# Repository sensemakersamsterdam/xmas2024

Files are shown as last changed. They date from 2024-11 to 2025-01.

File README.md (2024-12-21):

# 2024 Christmas project

A colaboration between:
- The Sensmakers Amsterdam IoT community: www.sensemakersams.org
- The Amsterdam Public Library: www.oba.nl
- in2tech: www.in2tech.nl
- Matanga: www.matanga.nl

Subdirectories:
- *src* for the python source files,
- *elec* for the schematics and PCB design in KiCad, PDF and JLCPCB manifacture formats,
- *case* for the design of the case and acrylic parts of the case.

For more info consult [https://sensemakersams.org/xmas-2024-acrylic-lamp/](https://sensemakersams.org/xmas-2024-acrylic-lamp/)

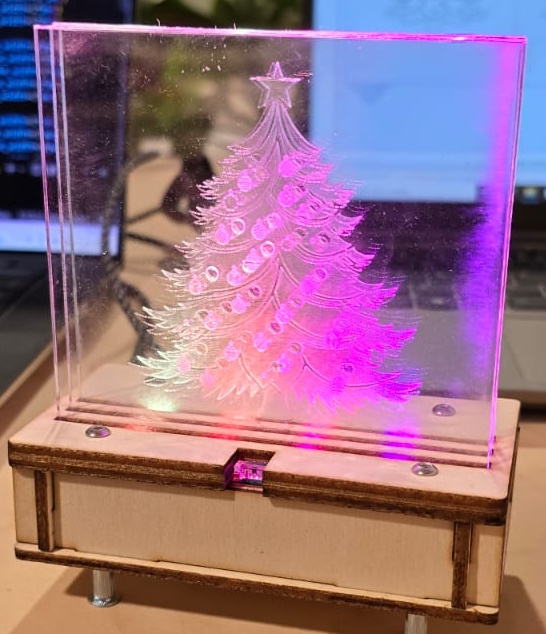
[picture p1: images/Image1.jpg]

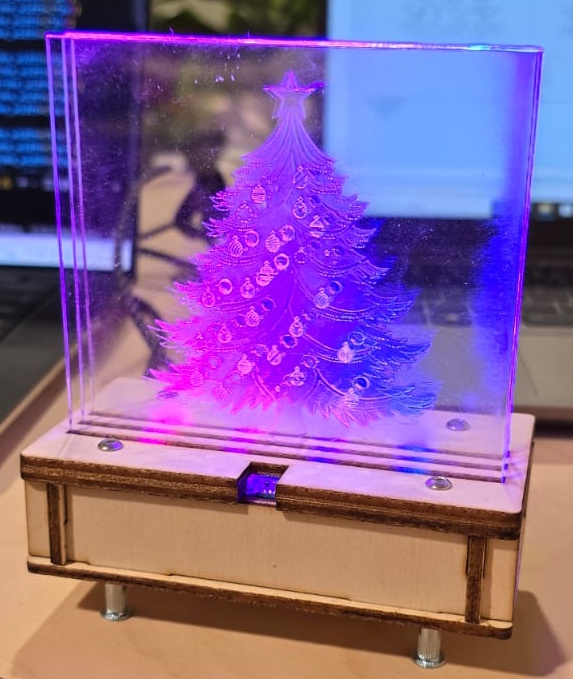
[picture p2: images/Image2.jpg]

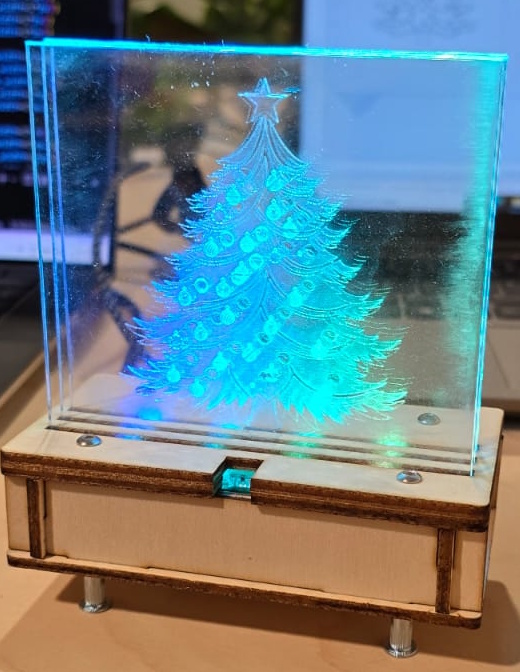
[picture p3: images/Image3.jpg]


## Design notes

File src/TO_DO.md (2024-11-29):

# To Do
## Must do
- More effects
- Driver and proper integration of the VEML7700
- Overall project documentation.
## Wish list
- Color setting by name
- Logging output to (rotated) file
- Logging output to MQTT
- Commands (which?) via MQTT
- Adding an embedded u-webserver to set parameters, like WiFI credentials and controlling effects manually.
- X-mas forests of communicating x-mas trees.
## Quality improvements
- Adding of tests.
- Watchdog timer

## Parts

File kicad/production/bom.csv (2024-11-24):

Designator | Footprint | Quantity | Value | LCSC Part #
C1, C2, C3, C4, C5 | 0805 | 5 | 100nF | C49678
D1, D10, D11, D12, D2, D3, D4, D5, D6, D7, D8, D9 | LED_WS2812B_PLCC4_5.0x5.0mm_P3.2mm | 12 | WS2812B | C2874885
R1, R2 | 0805 | 2 | 4k7 | C17673
R3 | 0805 | 1 | 330 | C17630
U2 | XDCR_VEML7700-TR | 1 | VEML7700-TR | C504893

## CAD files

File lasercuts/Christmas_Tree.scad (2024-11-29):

//Height Settings (for each color assign the extrusion height in mm, this is the height of the model that you will need to swap the plastic over)
print_thickness = 1.5;
plate_thickness = 3;
plate_width = 40;
plate_length = 60;
tree_dist = 7;
bold_dia=2.8;
bold_dia_2 = 2.2;
blind_klink_dia = 4.8;
led_dia=4;
led_size = [5, 5, 2];
$fn=32;

bold_dist = [37, 19.5];
print_size = [2*bold_dist[0] + 6, 2 * bold_dist[1] + 6];

tree_size = [print_size[0], 100];
led_center_x = [-30, -10, 10, 30];
led_center_y = [-2.25, 5.175, 12.675];

mount_center_x = [-37, 37];
mount_center_y = [22.5 - 3, -22.5 + 3];

tb_size = [110, 60];
rb_dia = 5;

// choose one of the following
//mode = "3D";
mode = "2D";
// mode = "plate";


if (mode == "3D")
{
    color("white") 
    for(y = led_center_y)
    { 
        translate([0, y, -20])
        translate([0, 1.5, 0])
            rotate([90, 0, 0])
                linear_extrude(3)
                    plate();    
    }

    color("green")
    print();

    color("aqua", .5)
    translate([0, 0, -21.5])
    linear_extrude(3)
    bottom();

    color("lightblue")
    translate([0, 0, 4.5])
    linear_extrude(3)
    top();

    color("lightgreen")
    translate([0, 0, 1.5])
    linear_extrude(3)
    top1();

    color("lightgray")
    translate([0, 0, 1.5])
        linear_extrude (height=led_size[2])
            leds();

    color("lightgray")
    translate([0, 20, 2.5])
        cube([8, 4, 4], center=true);

    color("pink")
    translate([(8.5 - (tb_size[0]/2)), 0, -8.5])
    rotate([90, 0, 90])
    linear_extrude(3, center=true) side();

    color("pink")
    translate([-(8.5 - (tb_size[0]/2)), 0, -8.5])
    rotate([90, 0, 90])
    linear_extrude(3, center=true) side();

    color("orange")
    translate([0, 26, -8.5])
    rotate([90, 0, 0])
    linear_extrude(3, center=true) front();

    color("orange")
    translate([0, -26, -8.5])
    rotate([90, 0, 0])
    linear_extrude(3, center=true) back();
}
else if (mode == "2D")
{
    color("aqua", .5)
    translate([0, 50])
    bottom();

    color("lightblue")
    translate([0, 112])
    top();

    color("lightgreen")
    translate([0, 174])
    top1();

    color("pink")
    translate([0, 265])
    side();

    color("pink")
    translate([0, 175])
    side();

    color("orange")
    translate([0, 220])
    front();

    color("orange")
    translate([0, 250])
    back();
}
else if (mode == "plate")
{
    color("white") 
        translate([0, -120])
            plate();    
    color("white") 
        translate([101, -120])
            plate();    
    color("white") 
        translate([202, -120])
            plate();    
}


module bottom()
{
    difference()
    {
        top_bottom(blind_klink_dia);
        
        translate([-(tb_size[0]-17)/2, 0])
        square([3.1, 36.1], center=true);

        translate([(tb_size[0]-17)/2, 0])
        square([3.1, 36.1], center=true);
        
        
        translate([30, 26])
            square([20.1, 3.1], center=true);

        translate([-30, 26])
            square([20.1, 3.1], center=true);
        
        
        translate([30, -26])
            square([20.1, 3.1], center=true);

        translate([-30, -26])
            square([20.1, 3.1], center=true);
    }
}

module top()
{
    difference()
    {
        top_bottom(bold_dia);

        for(y = led_center_y)
            translate([0, y])
                square([100.1, 3.1], center=true);

        mount_holes();
        
*        translate([0, 25])
            square([8, 12], center=true);
    }
}



module top1()
{
    difference()
    {
        top_bottom(bold_dia);

        for(y = led_center_y)
            translate([0, y])
                square([100.1, 3.1], center=true);

        difference()
        {
            hull()
            {
                for(x = [-bold_dist[0], bold_dist[0]])
                    for(y = [-bold_dist[1], bold_dist[1]])
                        translate([x, y])
                            circle(d=6);
            }
            for(x = [-bold_dist[0], bold_dist[0]])
                for(y = [-bold_dist[1], bold_dist[1]])
                    translate([x, y])
                        circle(d=7);
        }
    
        translate([-(tb_size[0]-17)/2, 0])
        square([3.1, 36.1], center=true);

        translate([(tb_size[0]-17)/2, 0])
        square([3.1, 36.1], center=true);
        
        translate([30, 26])
            square([20.1, 3.1], center=true);

        translate([-30, 26])
            square([20.1, 3.1], center=true);
                        
        translate([0, 25])
            square([8, 10], center=true);
        
    }
}


module top_bottom(mount_dia)
{
    difference()
    {
        hull()
        {
            translate([ (tb_size[0] - rb_dia) / 2,  (tb_size[1] - rb_dia)/2]) circle(d=rb_dia);
            translate([ (tb_size[0] - rb_dia) / 2, -(tb_size[1] - rb_dia)/2]) circle(d=rb_dia);
            translate([-(tb_size[0] - rb_dia) / 2,  (tb_size[1] - rb_dia)/2]) circle(d=rb_dia);
            translate([-(tb_size[0] - rb_dia) / 2, -(tb_size[1] - rb_dia)/2]) circle(d=rb_dia);
        }
        mount_holes(mount_dia);
    }
}


module front()
{
    difference()
    {
        front_back();
    }
}

module back()
{
    difference()
    {
        front_back();

        translate([0, 10])
        square([90, 20], center=true);
        
        translate([7, 0])
        square([15, 12], center=true); 
    }
}

module front_back()
{
    difference()
    {
        union()
        {
            square([tb_size[0], 20], center=true);

            translate([30, 0])
            square([20, 26], center=true);

            translate([-30, 0])
            square([20, 26], center=true);
        }
        translate([-(tb_size[0]-17)/2, 5])
        square([3.1, 10.1], center=true);
        
        translate([(tb_size[0]-17)/2, 5])
        square([3.1, 10.1], center=true);
    }
}

module side()
{
    difference()
    {
        union()
        {
            square([tb_size[1], 20], center=true);
            square([36, 26], center=true);
        }
        for(y = led_center_y)
        {
            translate([y, 3.5])
                square([3.4, 20], center=true);
        }
        
        translate([(tb_size[1]-8)/2, -5])
        square([3.1, 10.1], center=true);
        
        translate([-(tb_size[1]-8)/2, -5])
        square([3.1, 10.1], center=true);
    }
}

module plate()
{
    difference()
    {
        translate([0, 60])
        square([100, 110], center=true);
        
        translate([0, 13.65])
        square([print_size[0] + 1, 20], center=true);
    }
}


module print()
{
    linear_extrude (height=print_thickness)
        printplate();
}

module printplate()
{
    difference()
    {
        hull()
        {
            for(x = [-bold_dist[0], bold_dist[0]])
                for(y = [-bold_dist[1], bold_dist[1]])
                    translate([x, y])
                        circle(d=6);
        }
        mount_holes(bold_dia);
        for(x = mount_center_x)
        for(y = led_center_y)
        {
            translate([x, y]) circle(d=bold_dia_2);
        }
    }
}

module leds()
{
    for(x = led_center_x)
    for(y = led_center_y)
    {
        translate([x, y]) 
            square([led_size[0], led_size[1]], center=true);
    }
}

module base_plate(is_mountplate=false)
{
    difference()
    {
        square([plate_length, plate_width], center = true);
        
        if(is_mountplate)
        {
            translate([0, tree_dist + plate_thickness/2, 0])
                treemounts(tw1);
            translate([0,  plate_thickness/2, 0])
                treemounts(tw2);
            translate([0, -tree_dist + plate_thickness/2, 0])
                treemounts(tw3);
            
            // leds
            for(x = [-22.5, -7.5, 7.5, 22.5])
                for(y = [-7.5, 0, 7.5])
                    translate([x, y])
                        circle(d=led_dia);
        }
        mount_holes(bold_dia);
    }
}


module mount_holes(mount_dia)
{
    // mount holes
    echo(bold_dist);
    for(x = mount_center_x)
        for(y = mount_center_y)
            translate([x, y])
                circle(d=mount_dia);
}

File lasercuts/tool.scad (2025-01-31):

difference()
{
    union()
    {
        circle(d=13);
        hull()
        {
        translate([0, -6]) circle(d=7);
        translate([0, -25]) circle(d=5.5);
        }
    }
translate([0, 5]) square([5.5, 10], center=true);
intersection()
{
square([5.5, 10], center=true);
rotate(120) square([5.5, 10], center=true);
rotate(240) square([5.5, 10], center=true);
}
}

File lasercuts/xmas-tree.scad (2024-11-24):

//Tree Measurements  
//Tree Height (not the extruded height) 
    th1 = 50; 
    th2 = 40;
    th3 = 30;
    th4 = 20;
//Tree Width 
    tw1 = 50;
    tw2 = 35;
    tw3 = 20;
    tw4 = 5;
//Tree Points (not adjustable yet, so please leave it at 3, but in future plans)
    tp = 3;


module tree1()
{
    union()
    {
        difference()
        {
            tree(th1, tw1, tp);
            tree(th2, tw2, tp);
        }
        treemounts(tw1);
    }
}

module tree2()
{
    union()
    {
        difference()
        {
            tree(th2, tw2, tp);
            tree(th3, tw3, tp);
        }
        treemounts(tw2);
    }
}

module tree3()
{
    union()
    {
        difference()
        {
            tree(th3, tw3, tp);
            tree(th4, tw4, tp);
        }
        treemounts(tw3);
    }
}

module treemounts(tw)
{
    translate([((tw/2) - (plate_thickness*2)), -plate_thickness/2])
        square([plate_thickness, plate_thickness], center = true);
    translate([-((tw/2) - (plate_thickness*2)), -plate_thickness/2])
        square([plate_thickness, plate_thickness], center = true);
}

module tree(th, tw, tp)
{
    tw2 = tw/2;

        // Tree calculations
    pw = tw/(2*(tp+1));
    ph = th/(tp);
    ht = tw/2;
   
  // Draw Tree (height 1)
    polygon (points = 
        [[-tw2, 0], 
        [tw2, 0], 
        [tw2 - (2 * pw), ph], 
        [tw2 - pw, ph], 
        [tw2 - (3*pw), 2*ph], 
        [tw2 - (2*pw), 2*ph], 
        [tw2 - (4*pw), 3*ph], 
        [-tw2 + 2 * pw, 2*ph], 
        [-tw2 + 3 * pw, 2*ph], 
        [-tw2 + pw, ph], 
        [-tw2 + 2 * pw, ph]
        ]);
}

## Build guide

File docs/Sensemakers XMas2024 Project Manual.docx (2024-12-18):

# Sensemakers Christmas Project 2024 Manual A DIY Acrylic LED Lamp

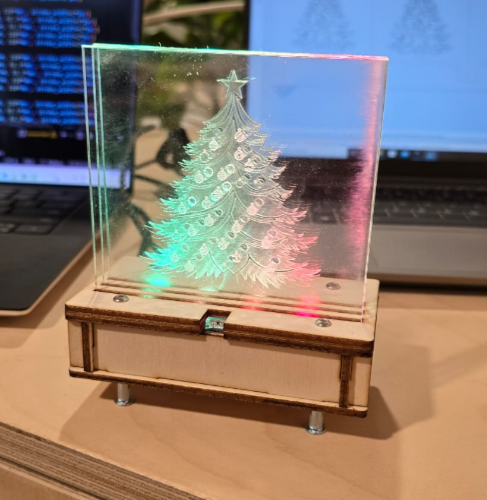
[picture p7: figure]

This holiday season, we’re excited to share a fun and engaging project with you! We’ve created a unique DIY kit featuring a programmable LED lamp powered by a custom PCB built around the Seeed Xiao microcontroller line. The kit is designed to be accessible for beginners while offering plenty of creative opportunities for experienced makers.

## Unpacking: what’s in the kit?

Your kit should contain the gollowing.

- Pre-cut wooden parts with nuts and bolts for assembling the case.
- Pre-cut acrylic slabs, available in two options:
  - Pre-engraved designs for instant festive flair.
  - Blank slabs for you to customize with our laser engraver in the OBA or manually using tools like a Dremel.
- Fully assembled PCB featuring:
  - 12 NeoPixel LEDs for vibrant, customizable light displays.
  - Ambient light sensor to adjust brightness or add reactive effects.
  - Four Grove connectors providing access to GPIO, I2C, SPI, or serial interfaces for easy expansion.
  - A Xiao ESP32S3 microcontroller, pre-soldered and pre-programmed with our basic Christmas-themed software.

Please compare your parts with the following pictures. And note that the acrylic slabs are not on the picture below, but three of them are included in your kit.

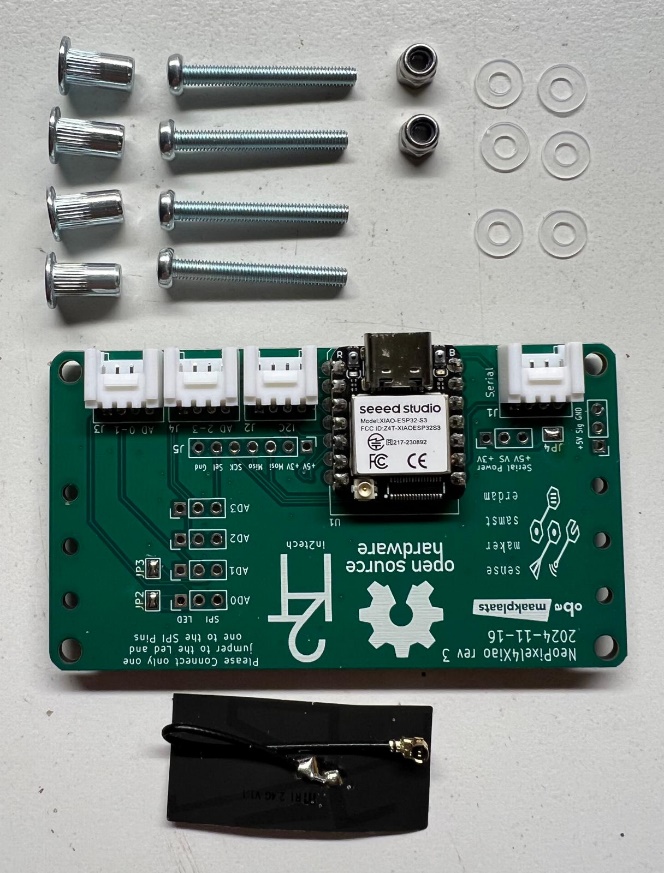
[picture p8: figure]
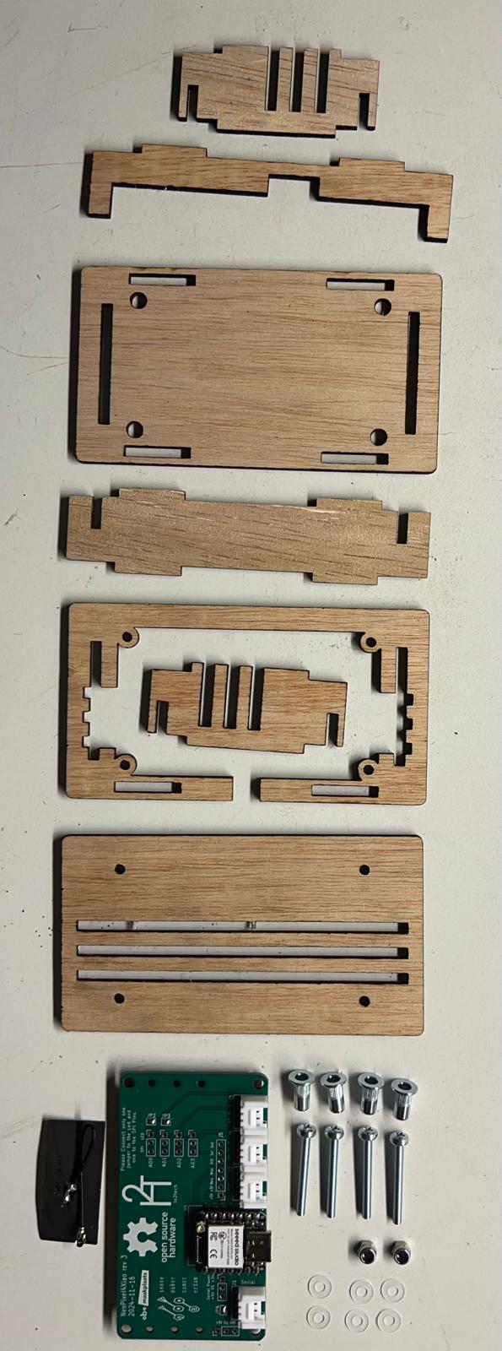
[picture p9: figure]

The wooden parts may contain remnants of the board they were cut from. Carefully remove them. Sometimes they may still be attached by some wood fibers at the bottom side, but they should come loose easily. Don’t break the parts you’re after. When in doubt, get help.

You also may need a bit of sandpaper for the final touch and to remove sooth around the engravings.

## Assembly

- Take the bottom board and carefully press the 4 “tube” nuts into the holes.
  - You should decide now if you want the Sensemakers logo on the bottom or not. If you don’t want it, just make it face the inside. In this manual we’ll keep the logo visible.
- The flange of the “tube” nuts should be on the outside, the tube should go through the board facing inwards.

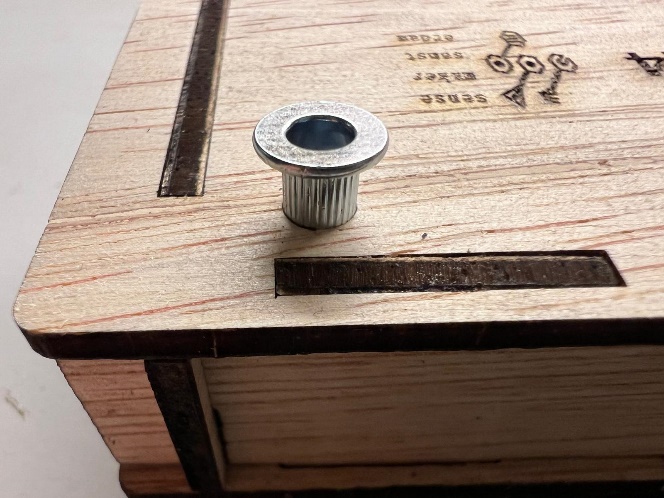
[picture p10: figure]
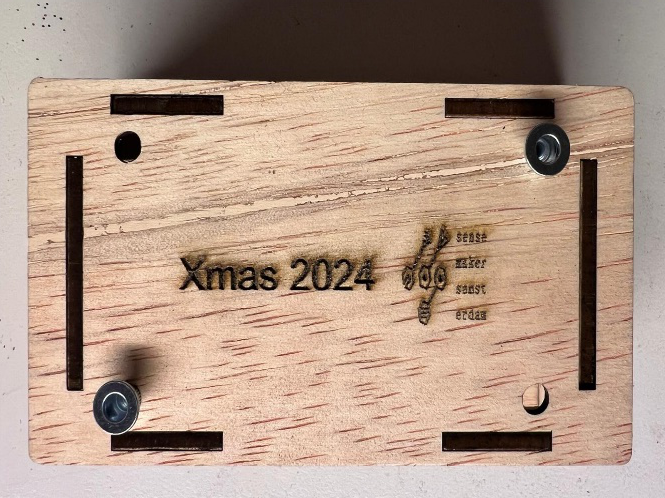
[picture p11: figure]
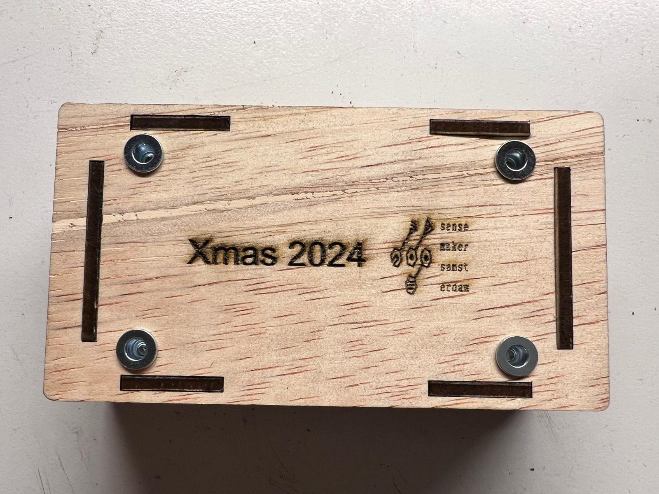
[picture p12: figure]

- Now takt the top board, this is the one with the three slits in it. Insert two of the bolts diagonally.
  - Make sure there is a plastic ring on the bolt before you insert it into the board. If the bolt doesn’t go in smoothly at frst, don’t force it. You may break the board. Just use a screwdriver to turn i tinto the board and keep turning until the resitance has gone. You kind of use the bolt as a drill.

When the holes need some enlarging, do it for all four now. Thats easier than doing the not yet used holes later.

  - It doesn’t matter which holes you use, as long as they are on a diagonal.

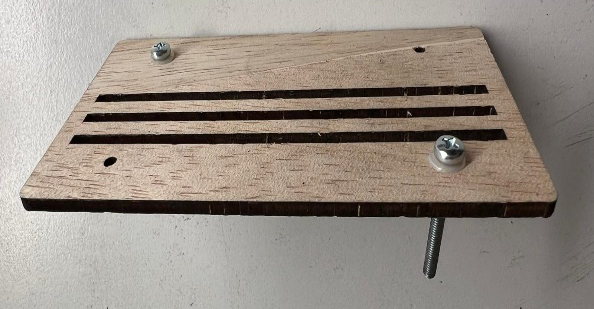
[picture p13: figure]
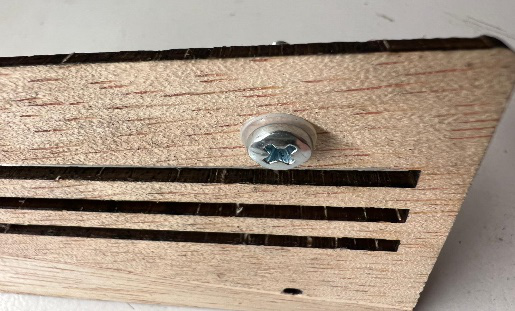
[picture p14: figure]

- Now it’s time to add the spacer. It should slide easily over the bolts. Again, you may need to enlarge them a wee bit, using one of the bolts and a screwdriver as a kind of drill. Be very careful, the spacer breaks easily.

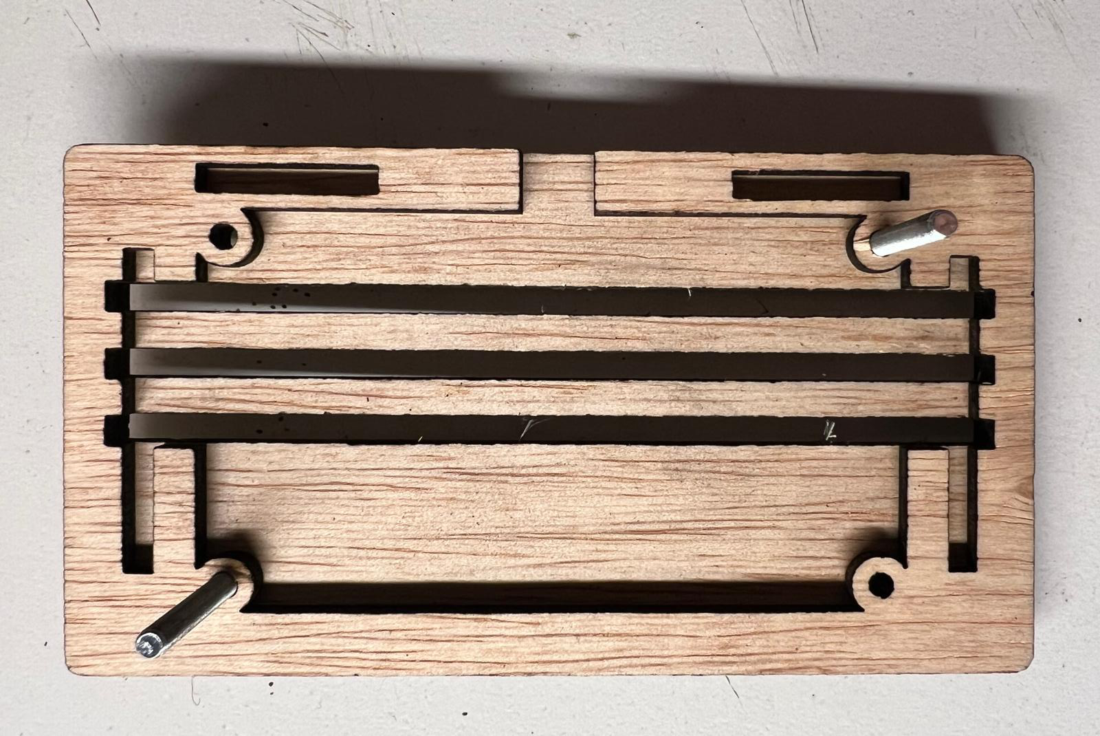
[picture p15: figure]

- And then the printed circuit board with the microprocessor, the light sensor and the LEDs follows. Make sure that it is oriented exactly as shown. When you turn it around, you should see the top of three LEDs through each of the slits.

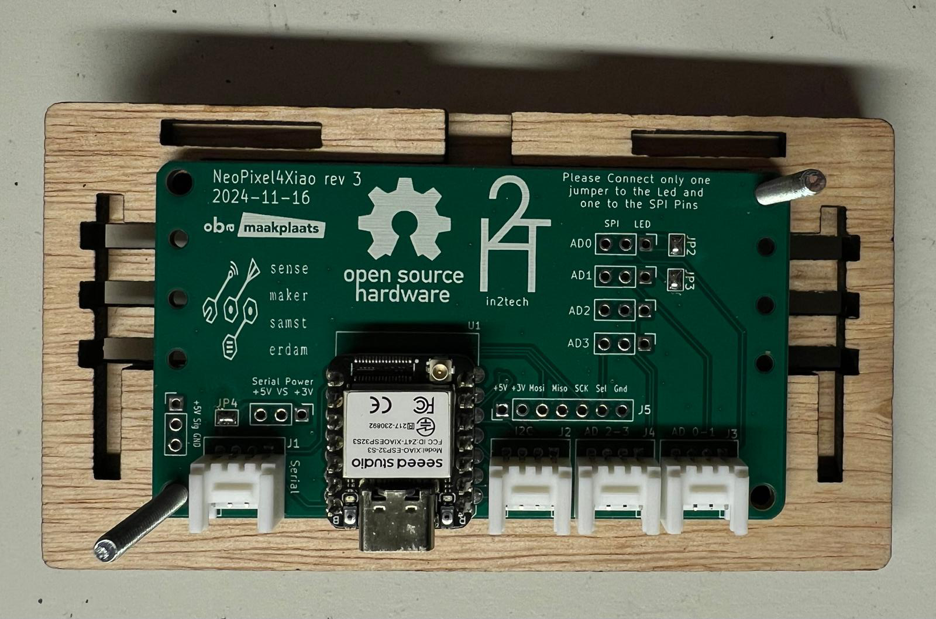
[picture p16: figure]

- Now put the remaining plastic rings on, one on each bolt.
  - They may not be exactly as shown below, but on the opposite corners. That is just fine.

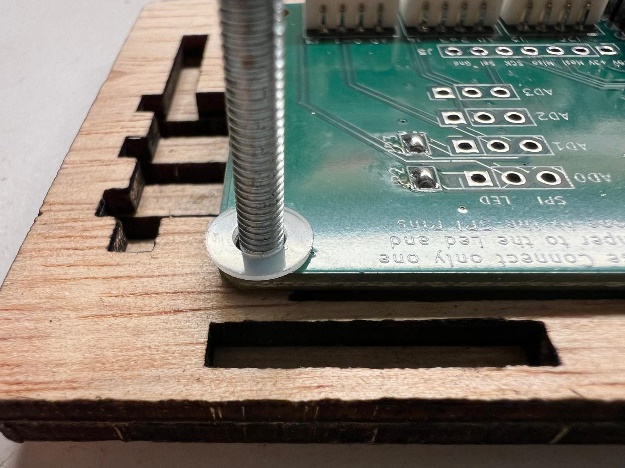
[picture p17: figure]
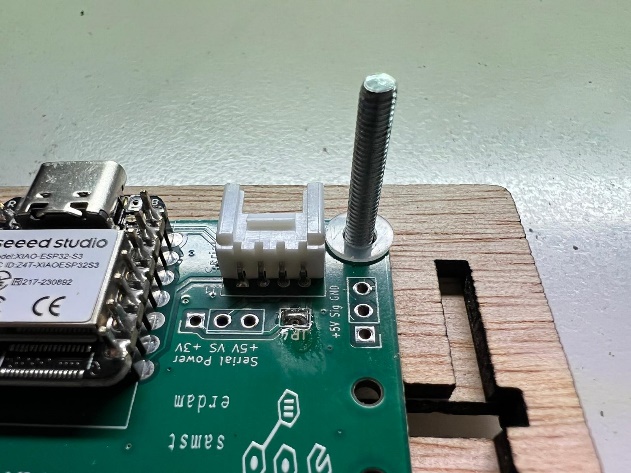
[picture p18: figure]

- Next put on the two remaining anti-slip nuts on the bolts and carefully thigten dem to fix the board to the top plate.
  - The nuts contain an anti-slip nylon insert. You’ll need plyers to hold the nut and a screwdriver to rotate the bolts.
  - Do not overtighten the nuts. You still need to be able to rotate the bolt with a screwdriver later to fix the bottom plate. So try this. If you cant turn the bolt, untighten the nut a wee bit until you can.

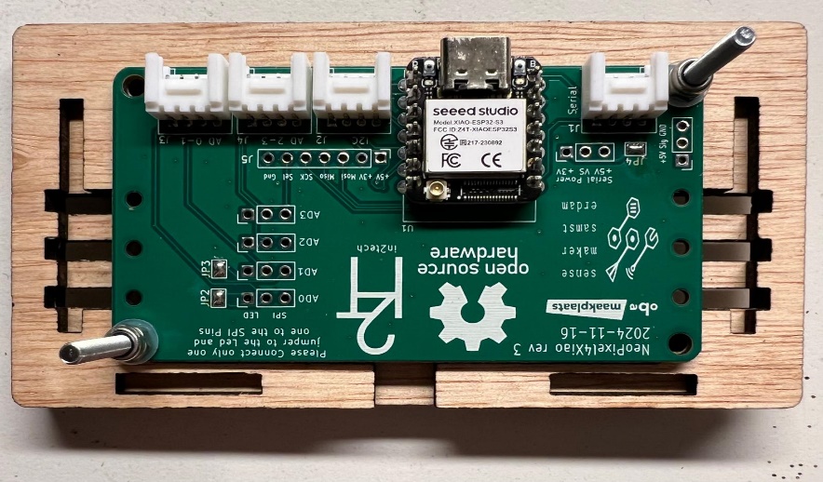
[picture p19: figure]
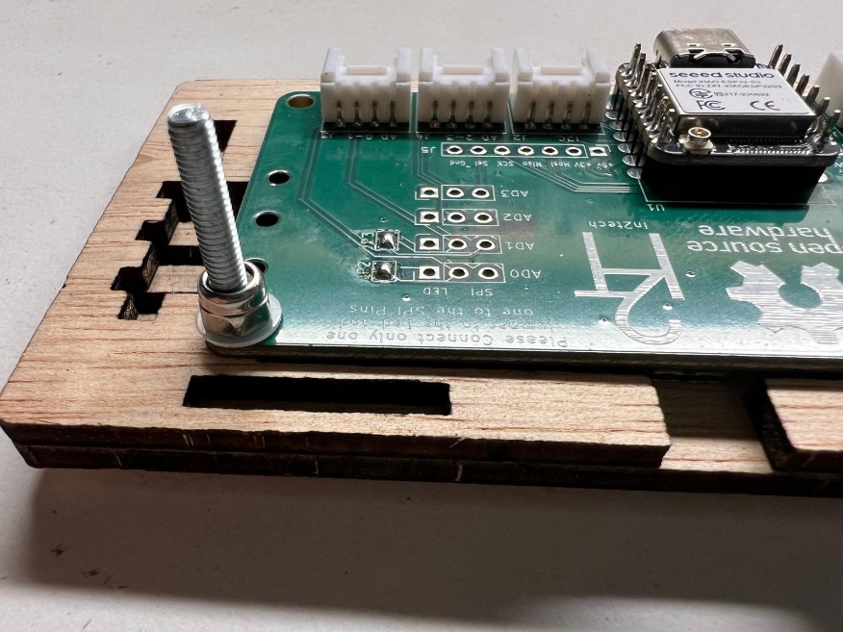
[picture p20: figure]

- Next insert the two small side boards (they are identical) into the side slits.
  - Be careful, they break easily. If you cannot press them in with a small bit of force, use some sand-paper to widen the slit a tiny bit.
  - Also make sure to attach the antenna (do not remove the paper from the antenna yet to expose the glue) to the board. The connector is a bit fragile. Make sure it is exactly above the other side on the board before you press. Ask for help when you are unsure.

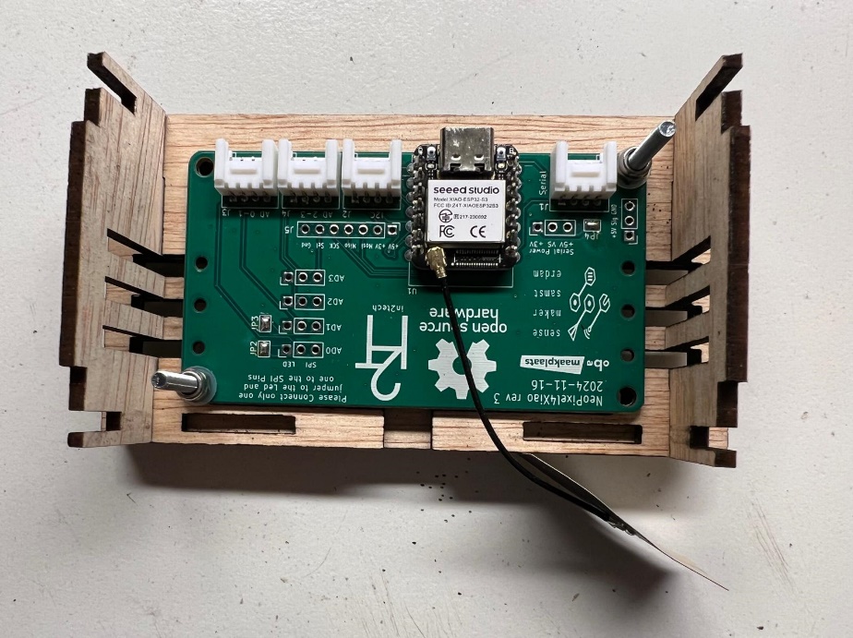
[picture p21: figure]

- Time to put in the bigger one of the long sides. Again, be careful and use sandpaper if required.

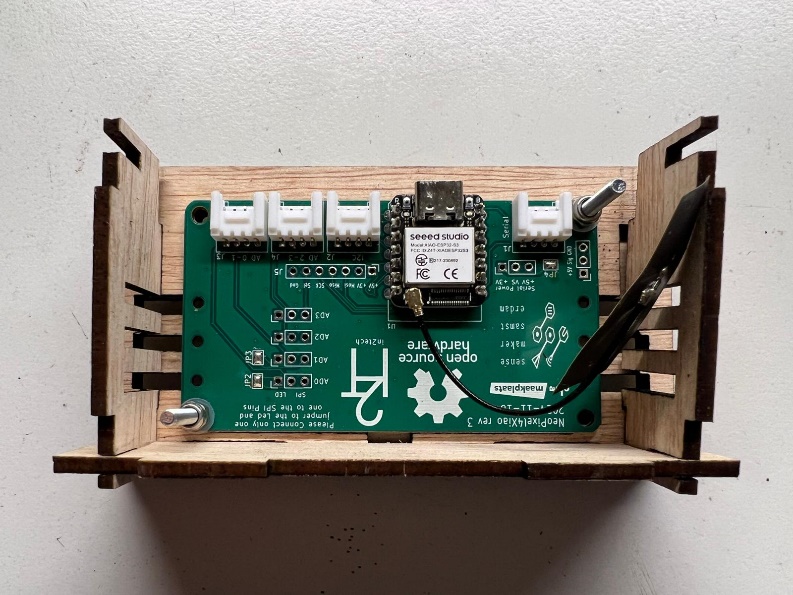
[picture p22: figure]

- Next the other long side. This is the smaller one. The text goes outside.
  - This part is quite thin in the middle. Breaks easily. You may want to try to fit it into the slots on the bottom plate and sand it up a bit if required first.
  - Now you also need to remove the paper protection from the antenna and glue it on the larger side panel. Make sure not to kink the cable!

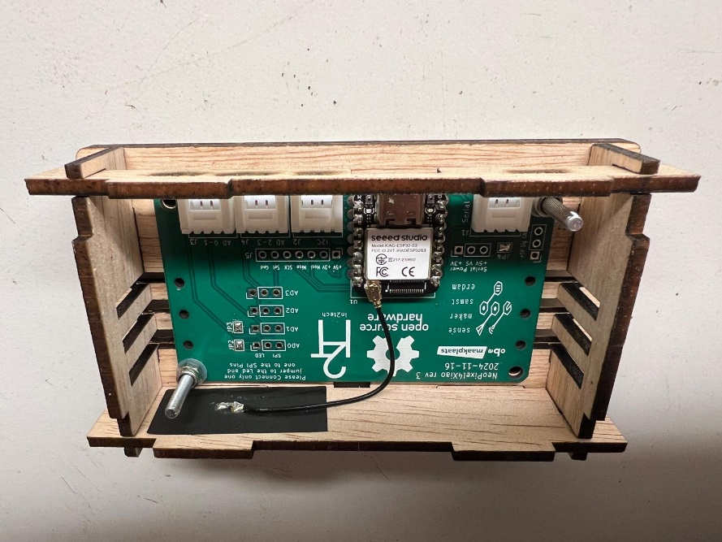
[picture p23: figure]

- Next mount the bottom plate.
  - If you have the text on the outside, make sure it has orientation you want.
  - Carefully put the bolts into the beginning of the “tube” nuts and turn the bolts with the screwdriver.
    - Don’t do this bolt after bolt, bit rotate the first one half a turn, then the second one, then the first one, and so on. This way the bottom plate stays in position for the fingers and slots on the wood.
  - As soon as the fingers on the side panels touch the slots in the bottom panel, make sure they are well positioned. When necessary, guide the fingers into the slot before you tighten the bolts further.
  - Do not overtighten. When you do the box will lose shape or break. Stop before the top or bottom boards start bending.
- Finally put a plastic ring on each of the remaining bolts and screw them in from the top.

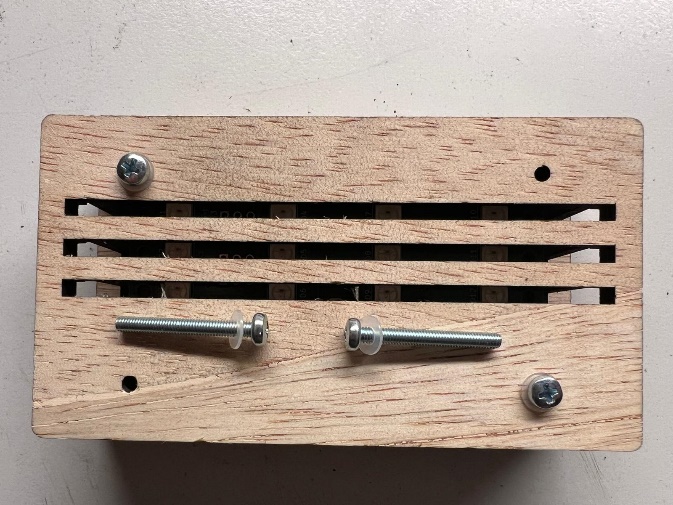
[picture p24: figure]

- The lamp feet should now look as below.

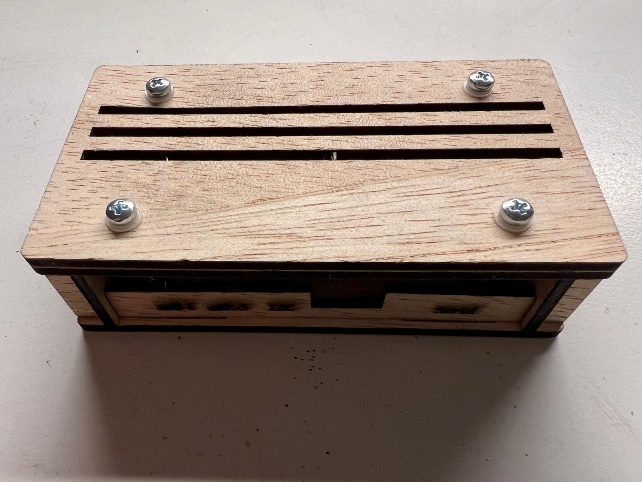
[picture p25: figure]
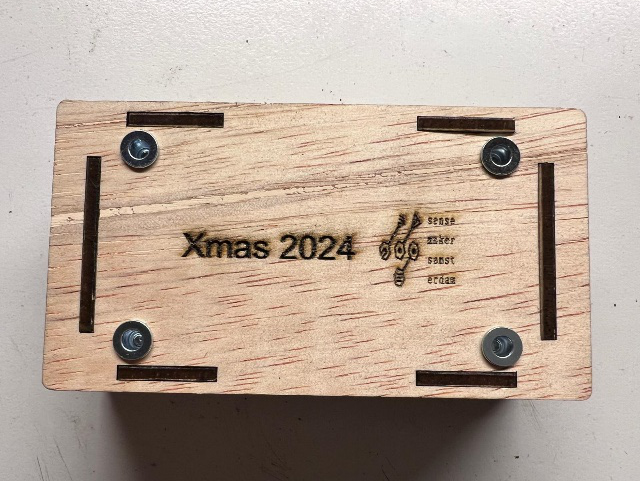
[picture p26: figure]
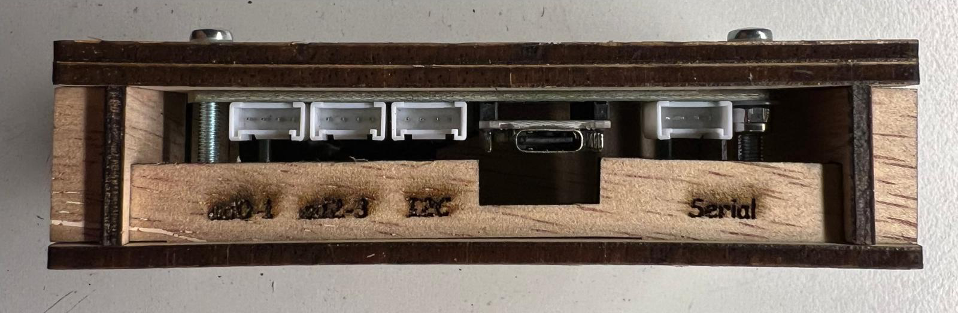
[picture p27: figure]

- We have a small number of self-gluing plastic thingies available to stick on as feet when you want to place the lamp on a sensitive surface. Ask for four when you need them and we have them.

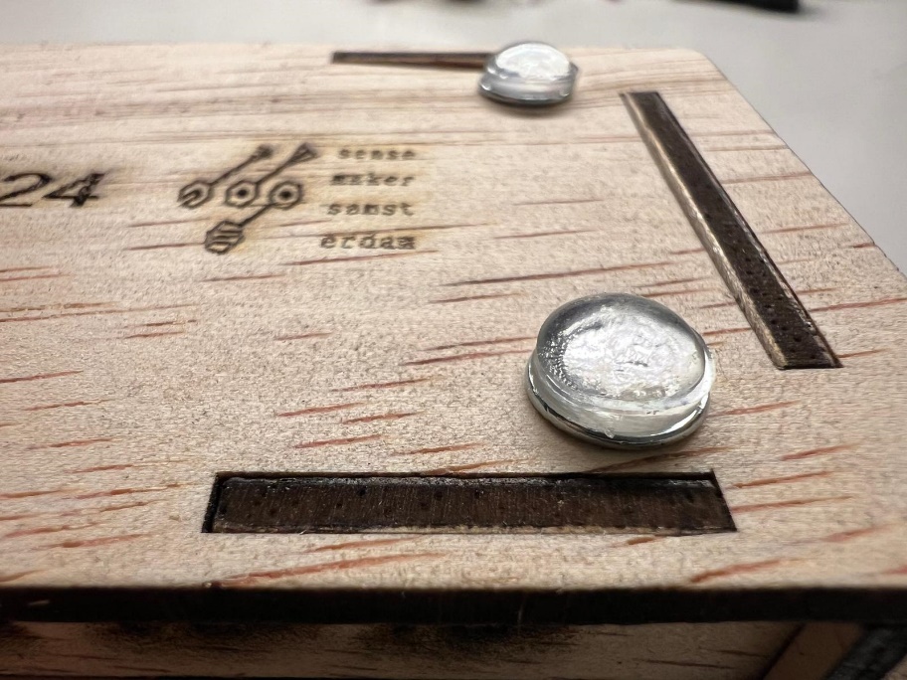
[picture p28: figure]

## And now

You need 3 acrylic slabs to finish the lamp. We have pre-engraved ones, or you can engrave some with our laser engraver (only with assistance), or manually engrave a slab with a Dremel. Please talk to us and we’ll get you going.

Please be very careful when inserting the acrylic slabs into the wooden base. Don’t tilt the slabs when pushing them in. You may need to widen the slits a bit first

And of course we will need to put the initial program onto your microcontroller and configure it for you to get the lamp going. This will be discussed in another paper.

# Have fun with your kit and a merry Christmas and a happy 2025 for you and your loved ones.

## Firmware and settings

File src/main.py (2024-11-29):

"""
Description: Xmas tree lights app using a NeoPixel matrix and MQTT for communication.
It includes functions to initialize settings and logging, connect to WiFi and MQTT, start effects,
and handle the main loop of the application.

Author: Gijs Mos, Sensemakers Amsterdam based on the original code by Karijn Wessing.
Maintainer: Sensemakers Amsterdam  https://sensemakersams.org

Functions:
- start_initial_effect(): Starts the initial effect for the application.
- init_settings_and_logging(): Initializes settings and logging.
- startup(): Initializes the device and sets up LED and effects.
- start_cloud(): Connects to WiFi and MQTT, and syncs time with NTP server.
- main(print_help=True, enable_cloud=True): Main function to run the device.
- allow_repl(): Allows REPL access by sleeping for 5 seconds.
"""

import gc
from random import choice
from time import sleep, ticks_diff, ticks_ms

import machine
import micropython
import neopixel
import pixellib
import senselogging as logging
import settings

from connectivity import (
    is_wifi_connected,
    mqtt_connect,
    mqtt_poll,
    mqtt_register_callback,
    ntp_sync_time,
    wifi_connect,
)
from effects import (
    effect_loop,
    full_help,
    get_effect_json,
    get_effects,
    init_effects,
    mqtt_effect_handler,
    start_effect_from_json,
)

GC_INTERVAL = 30000  # 30 seconds in ms between garbage collection runs

# Default settings, good for Xiao ESP32S3 with corresponding MicroPython firmware
# Override these in .env file if needed.
COLS = 4  # override with pix_columns setting
ROWS = 3  # override with pix_rows setting
PIXEL_PIN = 1  # override with pix_pin setting
SDA_PIN = 0  # override with sda_pin setting
SCL_PIN = 1  # override with scl_pin setting


def start_initial_effect():
    """
    Starts the initial effect for the application.

    This function retrieves the initial effect setting from the dot.env file. If the setting is
    not found, it selects a random effect from the available effects. The selected effect is then
    started.

    Returns:
        None
    """
    json_effect = settings.settings_get("initial_effect")
    logging.debug("Initial effect from settings: %s", json_effect)
    if json_effect is None:
        json_effect = get_effect_json(choice(get_effects()))
        logging.debug("Initial random effect: %s", json_effect)
    if json_effect is not None:
        start_effect_from_json(json_effect)
        logging.info("Started initial effect: %s.", json_effect)
        effect_loop()  # Run the effect first step
    else:
        logging.error("No initial effect found.")


def init_settings_and_logging():
    FMT = "%(asctime)s - %(levelname)s - %(message)s"
    logging.basicConfig(
        level=logging.INFO,
        format=FMT,
    )
    logging.info("Initializing settings and logging")
    settings.settings_load()
    level = settings.settings_get("log_level", "INFO")
    match_level = level.upper().strip()
    # Bit of a hack to get the logging level from the module
    for lvl_id, lvl_name in logging._level_dict.items():
        if lvl_name == match_level:
            logging.basicConfig(level=lvl_id, format=FMT)
            break
    else:
        logging.error("Invalid log level in settings: %s", level)


def startup():
    """
    Startup function to initialize the device.
    This function performs the following tasks:
    1. Allocates an emergency exception buffer for MicroPython.
    2. Prints a startup message to indicate the initialization of the Xmas Tree Lights Controller.
    3. Loads the settings using the `settings.load_settings()` method.
    4. Sets up the LED and effects by:
       - Retrieving the pixel pin, columns, and rows from the settings or using default values.
       - Initializing the NeoPixel object with the specified pin and total number of pixels.
       - Creating a NeoPixMatrix object with the initialized NeoPixel object, columns, and rows.
    5. Initializes the effects using the `init_effects(matrix)` function.
    """

    micropython.alloc_emergency_exception_buf(100)
    init_settings_and_logging()
    logging.info("Starting Xmas Tree Lights Controller.")

    # Setup LED & effects stuff
    pix_pin = int(settings.settings_get("pix_pin", PIXEL_PIN))
    pix_columns = int(settings.settings_get("pix_columns", COLS))
    pix_rows = int(settings.settings_get("pix_rows", ROWS))
    pixels = neopixel.NeoPixel(machine.Pin(pix_pin), pix_columns * pix_rows)
    matrix = pixellib.NeoPixMatrix(pixels, pix_columns, pix_rows)
    init_effects(matrix)


def start_cloud():
    """
    Connect to WiFi and MQTT and attempt to sync time with NTP server in the cloud.

    This function attempts to connect to a WiFi network and then to an MQTT broker.
    If the WiFi connection is successful, it proceeds to connect to the MQTT broker
    and synchronizes the time using NTP.

    Raises:
        ConnectionError: If the WiFi connection fails.
    """
    logging.info("Connecting to WiFi and MQTT")
    # We can re-use an existing STA connection, but will reconnect if not connected or AP.
    reconnect = is_wifi_connected() != "STA"
    if wifi_connect(reconnect=reconnect) == "STA":
        mqtt_register_callback("effect", mqtt_effect_handler)
        mqtt_connect()
        ntp_sync_time()
    else:
        logging.info(
            "No WiFi network connection available, AP mode only. No MQTT and NTP."
        )


def main(print_help=True, enable_cloud=True):
    """Main function to run the device."""
    startup()

    if enable_cloud:
        start_cloud()
    start_initial_effect()

    if print_help:
        print("\n" + full_help())

    last_gc = ticks_ms()
    try:
        while True:
            effect_loop()  # Run the effect's next step
            mqtt_poll()  # Poll for incoming MQTT messages
            if ticks_diff(ticks_ms(), last_gc) > GC_INTERVAL:
                gc.collect()
                last_gc = ticks_ms()

    except Exception as e:
        logging.exc(e, "An unhandled exception occurred.")
        logging.error("Re-booting the Xmas Tree Lights Controller.")
        # Give the logging module some time to write the error message
        # and prevent a fast reboot loop in case of a persistent error.
        sleep(20)
        machine.reset()
        while True:
            pass


def allow_repl():
    """Allow REPL access by sleeping for 5 seconds."""
    print(
        "You have 5 seconds to press Ctrl+C to stop the program and enter the REPL.",
        end="",
    )
    for i in range(10):
        print(".", end="")
        sleep(0.5)
    print()


if __name__ == "__main__":
    allow_repl()
    main()

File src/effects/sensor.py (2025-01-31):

"""
sensor.py - Adaptive cross effect.
Author: Karijn Wessing, Sensemakers Amsterdam
Maintainer: Sensemakers Amsterdam  https://sensemakersams.org
"""

import machine
import veml7700

from . import EffectBase, text2color

i2c = machine.I2C(1, scl=machine.Pin(1), sda=machine.Pin(0), freq=10000)


class Sensor(EffectBase):
    """
    Cross effect class to display a cross on the matrix.

    Attributes:
        help_purpose (str): Description of the effect's purpose.
        help_json (str): JSON representation of the effect.
        is_on (bool): Flag to determine if the cross is currently displayed.
        wait (int): Wait time in milliseconds between toggles.
        color (tuple): Color of the cross.
    """

    help_purpose = "Display a red cross on the matrix."
    help_json = '{ "effect": "sensor", "color": "(200,0,0)", "wait": 500 }'

    def __init__(self, matrix, params):
        """
        Initialize the Cross effect.

        Args:
            matrix: The matrix object to apply the effect on.
            params: Additional parameters for the effect.
        """
        super().__init__(matrix, params)
        self._is_on = True
        self._wait = params.get("wait", 500)
        self.veml = veml7700.VEML7700(address=0x10, i2c=i2c, it=100, gain=1 / 8)
        # self._color = text2color(params)
        self._color = (0, 0, 0)

    def render(self):
        """
        Render the cross effect on the matrix.
        """
        if self._is_on:
            self._matrix.clear()
        else:
            m = self._matrix
            m.line(0, 0, m.n_rows - 1, m.n_cols - 1, color=self._color)
            m.line(m.n_rows - 1, 0, 0, m.n_cols - 1, color=self._color)
            m.write()

    def advance(self):
        """
        Advance the cross effect by toggling the display state.
        """
        self._is_on = not self._is_on
        lux = self.veml.read_lux()
        lux = int(lux / 10)
        if lux > 255:
            lux = 255
        if lux < 1:
            lux = 1
        self._color = (lux, int(lux / 2), int(lux / 4))


register = (Sensor,)

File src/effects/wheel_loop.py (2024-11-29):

"""
wheel_loop.py -  WheelLoop effect class.
Author: Karijn Wessing, Sensemakers Amsterdam
Maintainer: Sensemakers Amsterdam  https://sensemakersams.org
"""
from effects import EffectBase, wheel


class WheelLoop(EffectBase):
    """
    WheelLoop effect class to cycle through the matrix with a wheel effect.

    Attributes:
        help_purpose (str): Description of the effect's purpose.
        help_json (str): JSON representation of the effect.
        index (int): Current index for the wheel effect.
    """

    help_purpose = "Cycle through the matrix with a wheel effect."

    def __init__(self, matrix, params):
        """
        Initialize the WheelLoop effect.

        Args:
            matrix: The matrix object to apply the effect on.
            params (dict): Additional parameters for the effect.
        """
        super().__init__(matrix, params)
        self._index = 0

    def advance(self):
        """
        Advance the wheel effect by incrementing the index.

        Returns:
            None
        """
        self._index += 1

    def render(self):
        """
        Render the wheel effect on the matrix.
        """
        m = self._matrix
        msize = m.size()
        for i in range(msize):
            rc_index = (i * 256 // msize) + self._index
            m.set_index(i, wheel(rc_index & 255))
        m.write()


register = (WheelLoop,)

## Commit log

2024-11-07 Bug fixes in my changes. Doc strings added.
    [connectivity.py, cross.py, cycle.py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]
2024-11-10 added lasercuts
    [Christams_Tree.scad, xmas-tree.scad]
2024-11-13 added kicad
    [Christams_Tree.scad, bom.csv, designators.csv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]
2024-11-13 added missing kicad files
    [Grove - Vision AI Module V2.kicad_pcb, Grove - Vision AI Module V2.kicad_sch, Grove_Vision_AI_V2_BOM.xlsx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]
2024-11-13 Delete kicad/lib/Seeeduino XIAO-MOUDLE14P-2.54-21X17.8MM-holes.kicad_mod
    filename too long
2024-11-14 moved sensor.py to effects dir
2024-11-15 fixed symbol lib misc cleanups kikad directory and PCB
    [Christams_Tree.scad, Grove - Vision AI Module V2.kicad_pcb, Grove - Vision AI Module V2.kicad_sch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]
2024-11-15 minor fix-up silkscreens
    [bom.csv, designators.csv, positions.csv]
2024-11-16 PCB order included
2024-11-29 box-top without lightsensor hole
    [Christams_Tree.scad]
2024-11-29 bottom bold dia changed
    [Christams_Tree.scad]
2024-11-29 blind klink dia 4.8
    [Christams_Tree.scad]
2024-11-30 sensor.py works with these pins
2024-11-30 added texts ad01, ad23, I2C, and Serial
2024-12-18 Assembly manual and flyer added
2024-12-21 added pin low before write()
2025-01-31 added tool
    [tool.scad]
